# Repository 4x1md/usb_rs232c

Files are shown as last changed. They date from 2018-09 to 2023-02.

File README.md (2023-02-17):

# USB to RS-232C adapter
USB to RS-232C adapter based on CH340G and MAX232 ICs.

## Overview

The adapter was designed for communcating with arbitrary waveform generators which have RS-232 interface.

It uses CH340G IC as a USB-to-UART adapter and MAX232 for converting 5V UART logic levels to RS-232.

The device can also be used as USB-to-UART adapter if MAX232 IC is not assembled. 

## Schematic

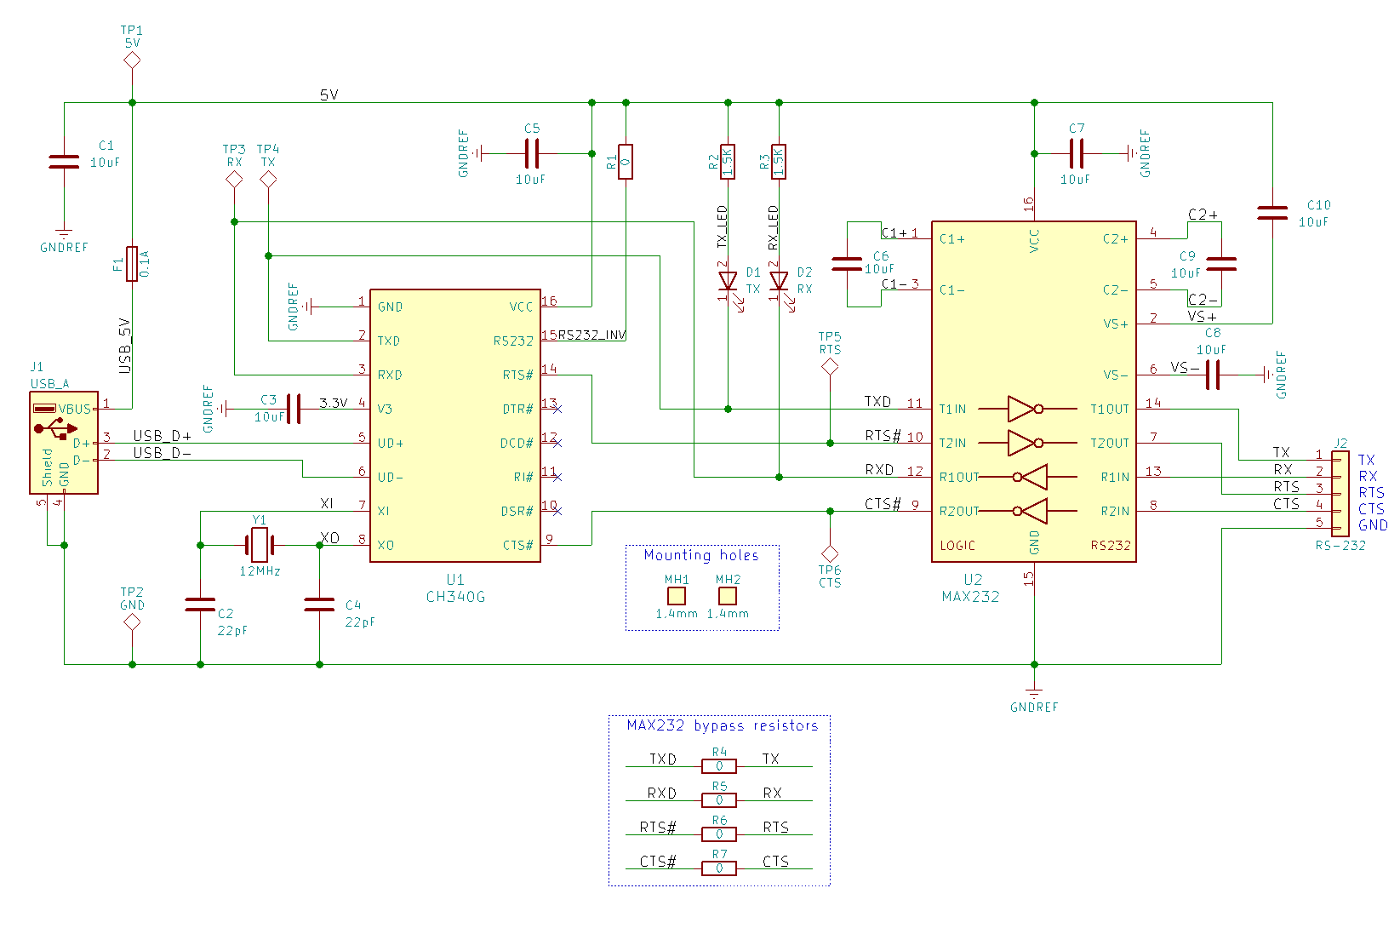
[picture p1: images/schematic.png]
Schematic


## BOM Variants

The device has two assembly options: USB to RS-232 adapter and USB to UART adapter.

### USB to RS-232 Adapter

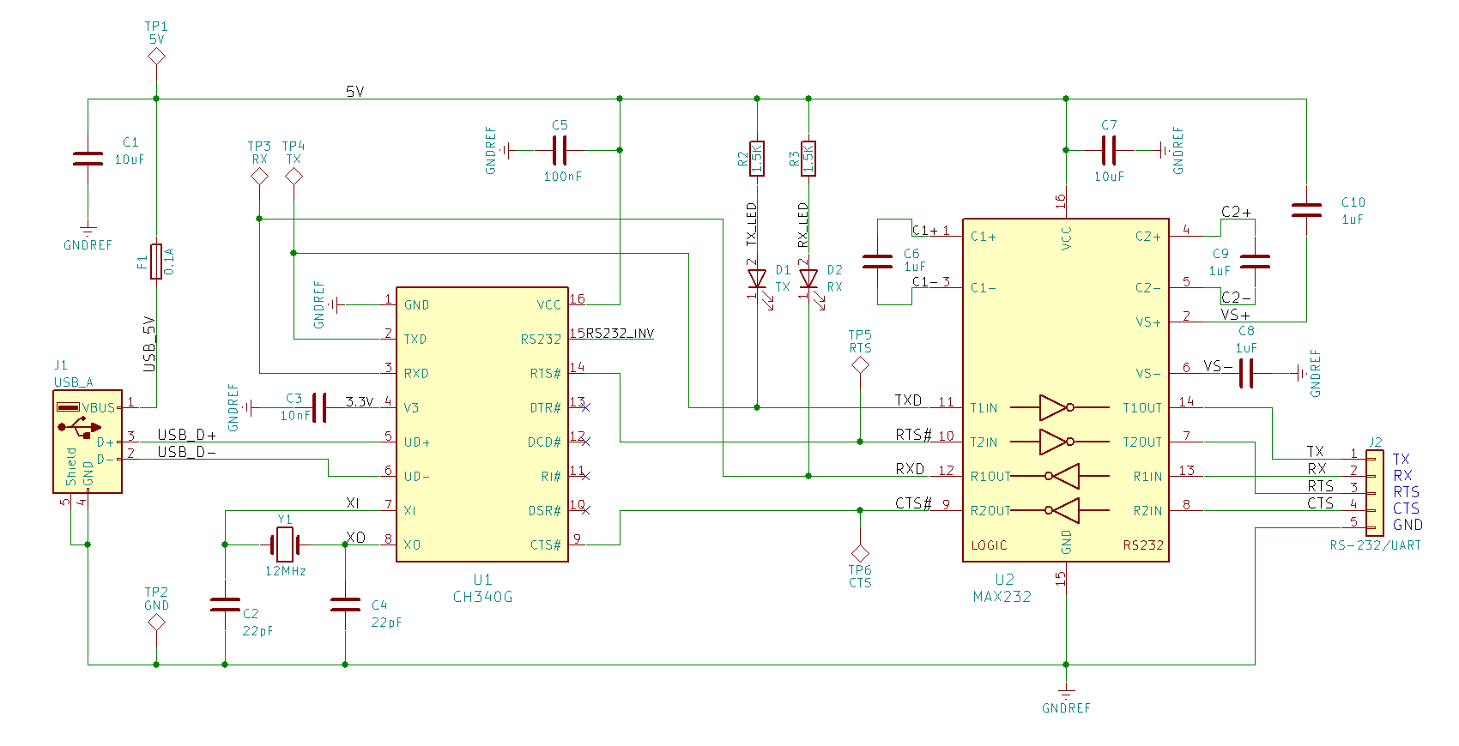
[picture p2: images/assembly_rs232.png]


### USB to UART Adapter

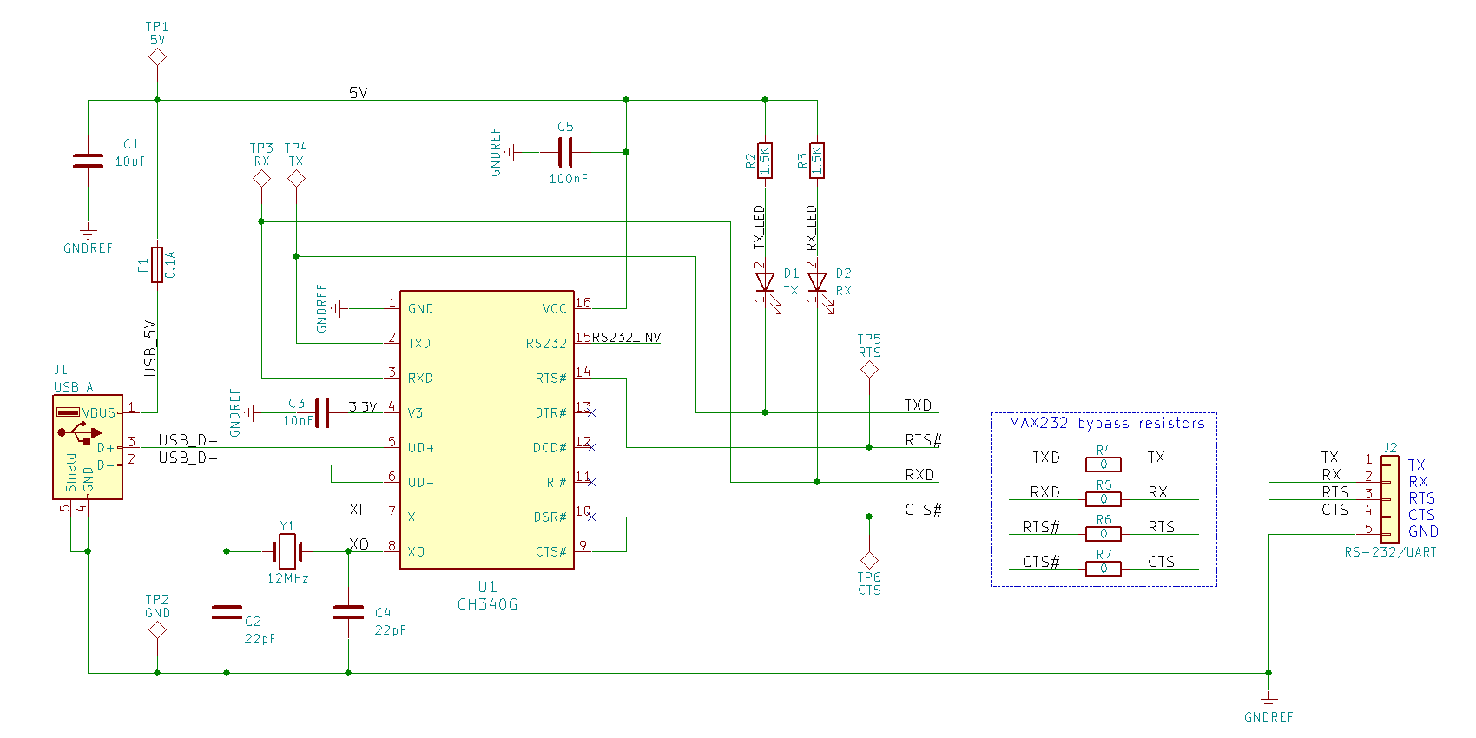
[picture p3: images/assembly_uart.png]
Photo UART


## PCB

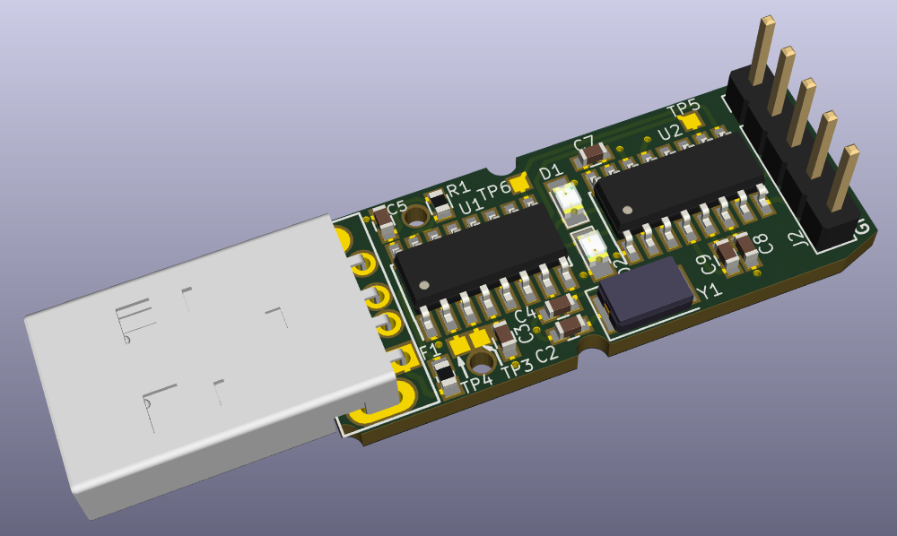
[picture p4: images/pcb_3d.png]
3D model


## Photos

### RS-232 Assembly

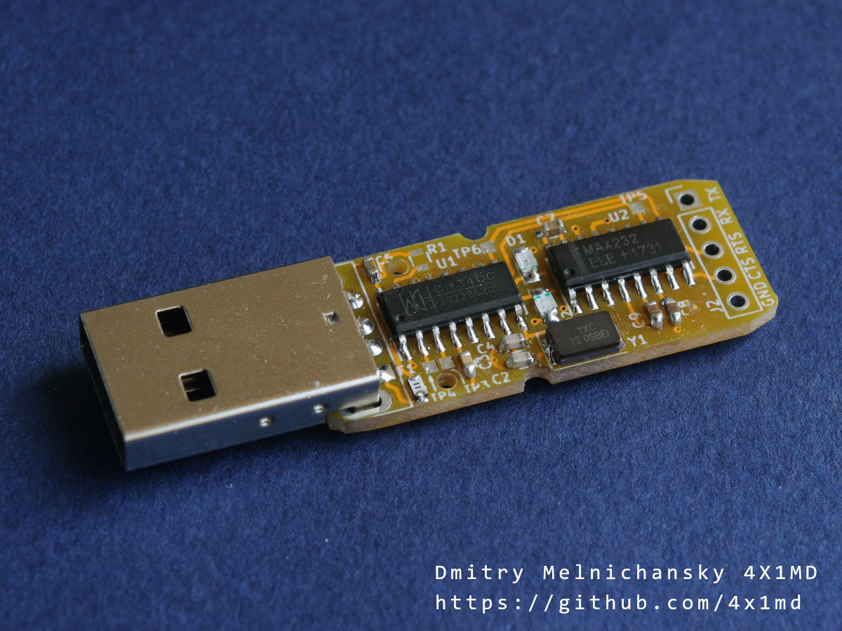
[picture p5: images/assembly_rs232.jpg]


### UART Assembly

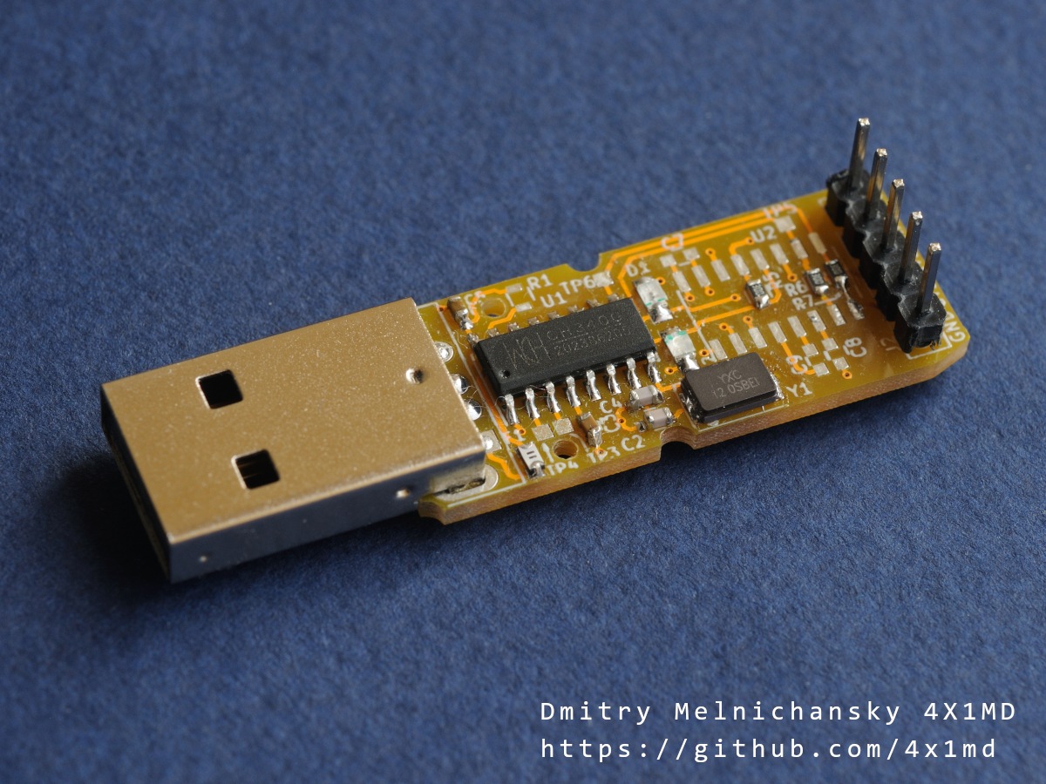
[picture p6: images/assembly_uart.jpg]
Photo UART


## Links

1. [CH340G USB to RS232 TTL module schematic (D-SUN-V3.0)](http://nicecircuits.com/ch340g-usb-to-rs232-ttl-module-schematic-d-sun-v3-0/)
2. [Various modules from china - schematic reverse engineering etc.](https://github.com/NiceCircuits/modules_from_china)
3. [Микросхема CH340G – преобразователь интерфейса USB в UART (мост USB-UART). Характеристики, условия эксплуатации, типовые схемы включения](http://mypractic.ru/mikrosxema-ch340g-preobrazovatel-interfejsa-usb-v-uart-most-usb-uart-xarakteristiki-usloviya-ekspluatacii-tipovye-sxemy-vklyucheniya.html)

## Questions? Suggestions?
You are more than welcome to contact me with any questions, suggestions or propositions regarding this project. You can:

1. Visit [my QRZ.COM page](https://www.qrz.com/db/4X1MD)
2. Visit [my Facebook profile](https://www.facebook.com/Dima.Meln)
3. Write me an email to iosaaris =at= gmail dot com

## How to Support or Say Thanks

If you like this project, or found here some useful information and want to say thanks, or encourage me to do more, you can buy me a coffee!



"Buy Me A Coffee" (https://www.buymeacoffee.com/4x1md)

You can aslo make a donation with PayPal:



---

**73 de 4X1MD**

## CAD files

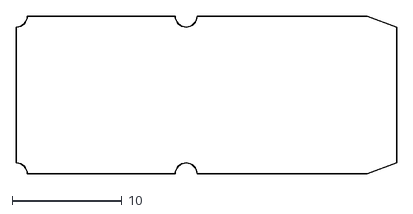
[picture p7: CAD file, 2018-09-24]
mechanics/pcb.dxf
34.7 x 14.4

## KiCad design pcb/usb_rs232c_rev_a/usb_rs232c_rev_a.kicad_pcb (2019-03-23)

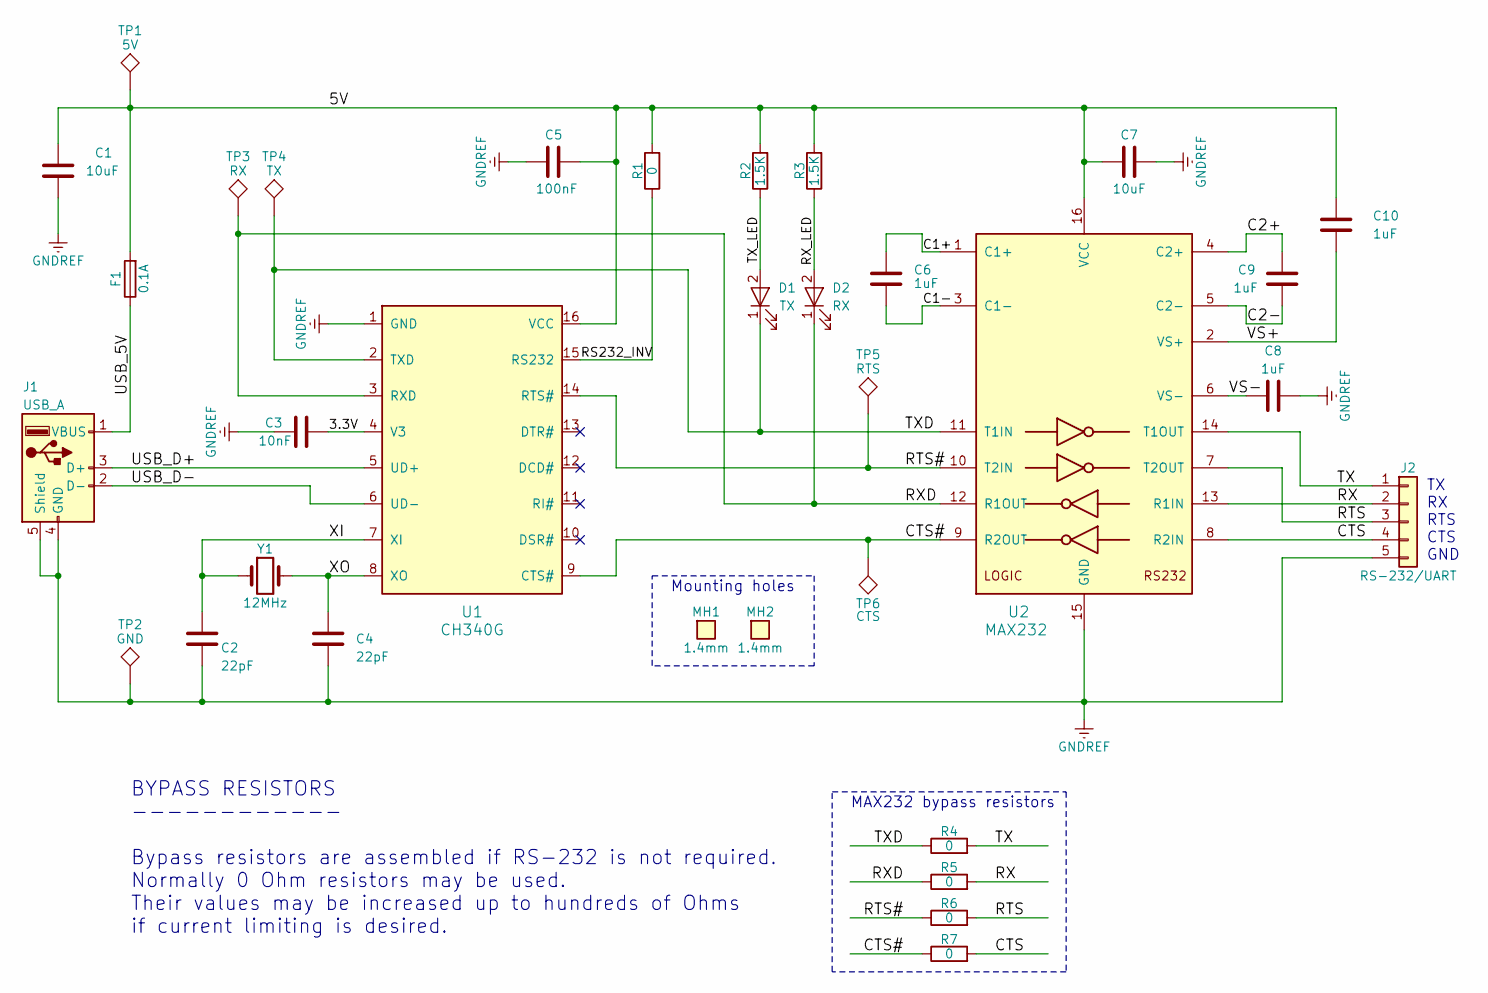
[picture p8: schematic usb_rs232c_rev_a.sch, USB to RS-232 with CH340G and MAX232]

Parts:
C1, C7: 10uF; C_0603
C2, C4: 22pF; C_0603
C3: 10nF; C_0603
C5: 100nF; C_0603
C6, C8, C9, C10: 1uF; C_0603
D1: TX; LED_0805
D2: RX; LED_0805
F1: 0.1A; Fuse_0603
J1: USB_A; USB_A_Male_THT
J2: RS-232/UART; Pin_Header_Straight_1x05_Pitch2.54mm
MH1, MH2: 1.4mm; MountingHole_1.4mm
R1, R4, R5, R6, R7: 0; R_0603
R2, R3: 1.5K; R_0603
TP1: 5V; Measurement_Point_Square-SMD_1.0mmx1.0mm
TP2: GND; Measurement_Point_Square-SMD_1.0mmx1.0mm
TP3: RX; Measurement_Point_Square-SMD_1.0mmx1.0mm
TP4: TX; Measurement_Point_Square-SMD_1.0mmx1.0mm
TP5: RTS; Measurement_Point_Square-SMD_1.0mmx1.0mm
TP6: CTS; Measurement_Point_Square-SMD_1.0mmx1.0mm
U1: CH340G; SOIC-16_3.9x9.9mm_Pitch1.27mm
U2: MAX232; SOIC-16_3.9x9.9mm_Pitch1.27mm
Y1: 12MHz; Crystal_SMD_5032-2pin_5.0x3.2mm

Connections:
/3.3V: C3.2, U1.4 (V3)
/5V: C1.1, C5.1, C7.2, C10.1, F1.2, R1.2, R2.2, R3.2, TP1.1, U1.16 (VCC), U2.16 (VCC)
/C1+: C6.1, U2.1 (C1+)
/C1-: C6.2, U2.3 (C1-)
/C2+: C9.1, U2.4 (C2+)
/C2-: C9.2, U2.5 (C2-)
/CTS: J2.4, R7.2, U2.8 (R2IN)
/CTS#: R7.1, TP6.1, U1.9 (CTS#), U2.9 (R2OUT)
/RS232_INV: R1.1, U1.15 (RS232)
/RTS: J2.3, R6.2, U2.7 (T2OUT)
/RTS#: R6.1, TP5.1, U1.14 (RTS#), U2.10 (T2IN)
/RX: J2.2, R5.2, U2.13 (R1IN)
/RXD: D2.1 (K), R5.1, TP3.1, U1.3 (RXD), U2.12 (R1OUT)
/RX_LED: D2.2 (A), R3.1
/TX: J2.1, R4.2, U2.14 (T1OUT)
/TXD: D1.1 (K), R4.1, TP4.1, U1.2 (TXD), U2.11 (T1IN)
/TX_LED: D1.2 (A), R2.1
/USB_5V: F1.1, J1.1 (VBUS)
/USB_D+: J1.3 (D+), U1.5 (UD+)
/USB_D-: J1.2 (D-), U1.6 (UD-)
/VS+: C10.2, U2.2 (VS+)
/VS-: C8.2, U2.6 (VS-)
/XI: C2.1, U1.7 (XI), Y1.1
/XO: C4.1, U1.8 (XO), Y1.2
GNDREF: C1.2, C2.2, C3.1, C4.2, C5.2, C7.1, C8.1, J1.4 (GND), J1.5 (Shield), J2.5, TP2.1, U1.1 (GND), U2.15 (GND)

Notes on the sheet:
TX RX RTS CTS GND
Mounting holes
BYPASS RESISTORS ------------ Bypass resistors are assembled if RS-232 is not required. Normally 0 Ohm resistors may be used. Their values may be increased up to hundreds of Ohms if current limiting is desired.
MAX232 bypass resistors

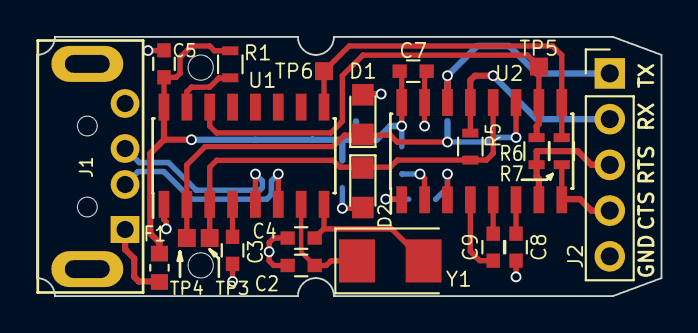
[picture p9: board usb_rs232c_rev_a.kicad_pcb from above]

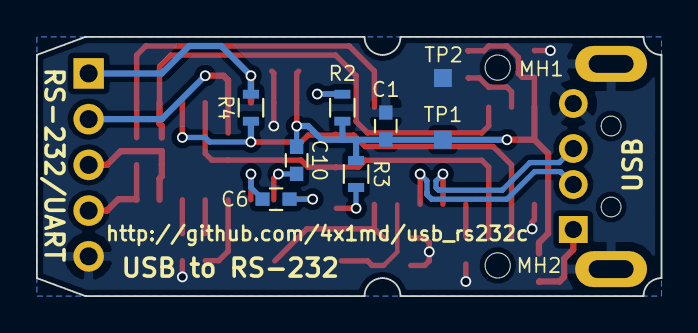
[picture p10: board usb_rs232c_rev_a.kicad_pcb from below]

Board: 2 copper layers, 34.7 x 14.4 mm, 33 parts (8 on the bottom side), 25 nets.

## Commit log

2018-03-24 PCB mechanical drawing.
    [pcb.dxf]
2018-08-31 PCB production files.
    [usb_rs232c_rev_a-B.Cu.gbr, usb_rs232c_rev_a-B.Mask.gbr, usb_rs232c_rev_a-B.SilkS.gbr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]
2018-08-31 Readme and DXF.
    [pcb.dxf]
2018-09-24 Updated PCB after the first iteration.
    [pcb.dxf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]
2018-10-01 3D model of PCB.
2019-01-25 1. Added bypass resistors for MAX232. 2. Updated README.md
    [usb_rs232c_rev_a-B.Cu.gbr, usb_rs232c_rev_a-B.Mask.gbr, usb_rs232c_rev_a-B.SilkS.gbr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]
2019-03-23 Schematics update.
    [usb_rs232c_rev_a.kicad_pcb, usb_rs232c_rev_a.sch]
